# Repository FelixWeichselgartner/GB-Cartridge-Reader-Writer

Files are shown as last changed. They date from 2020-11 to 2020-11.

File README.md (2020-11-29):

# GB-Cartridge-Reader-Writer

This is an Arduino Shield, that can be used to dump GameBoy cartridges. This project is strongly inspired by this project:

* https://www.insidegadgets.com/2011/03/19/gbcartread-arduino-based-gameboy-cart-reader-%E2%80%93-part-1-read-the-rom/
* https://github.com/insidegadgets/GBCartRead

The code in this repo is based on this, however I did a lot of changes to the Arduino code.

shield_top

shield_bottom

# Tested ROMs

| Game | Dump ROM | Dump RAM | Upload RAM |
|---|---|---|---|
| Tetris (no MBC) | yes | N/A | N/A |
| Yoshi's Cookie (MBC1)  | yes | N/A | N/A |
| Pokémon Red (MBC5) | yes | ? | ? |
| Pokémon Yellow (MBC5)  | yes | yes | ? |
| Pokémon TCG (MBC5) | yes | yes | ? |

GBC is not supported so far.

# Eagle Layout for the Arduino shield

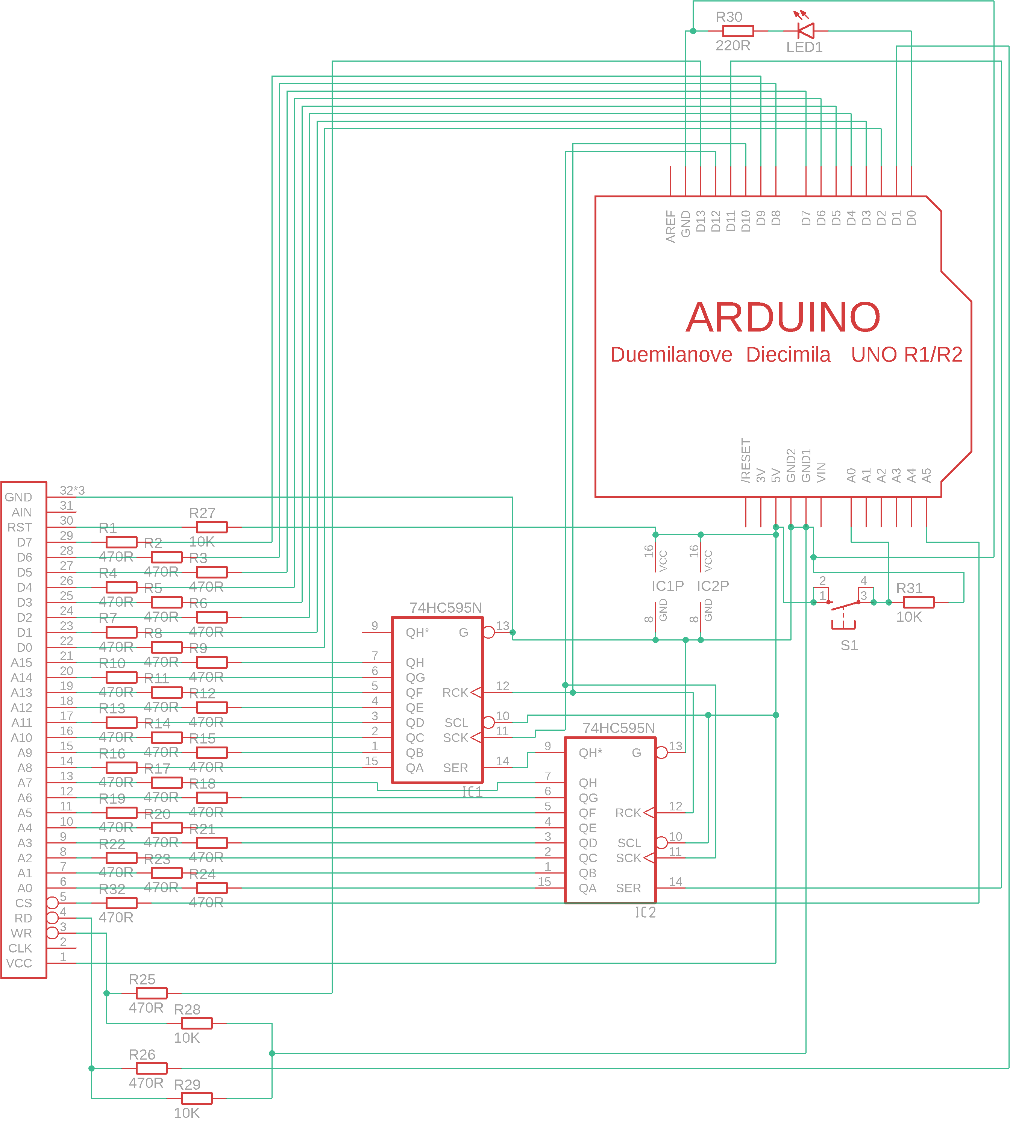
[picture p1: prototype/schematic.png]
schematic


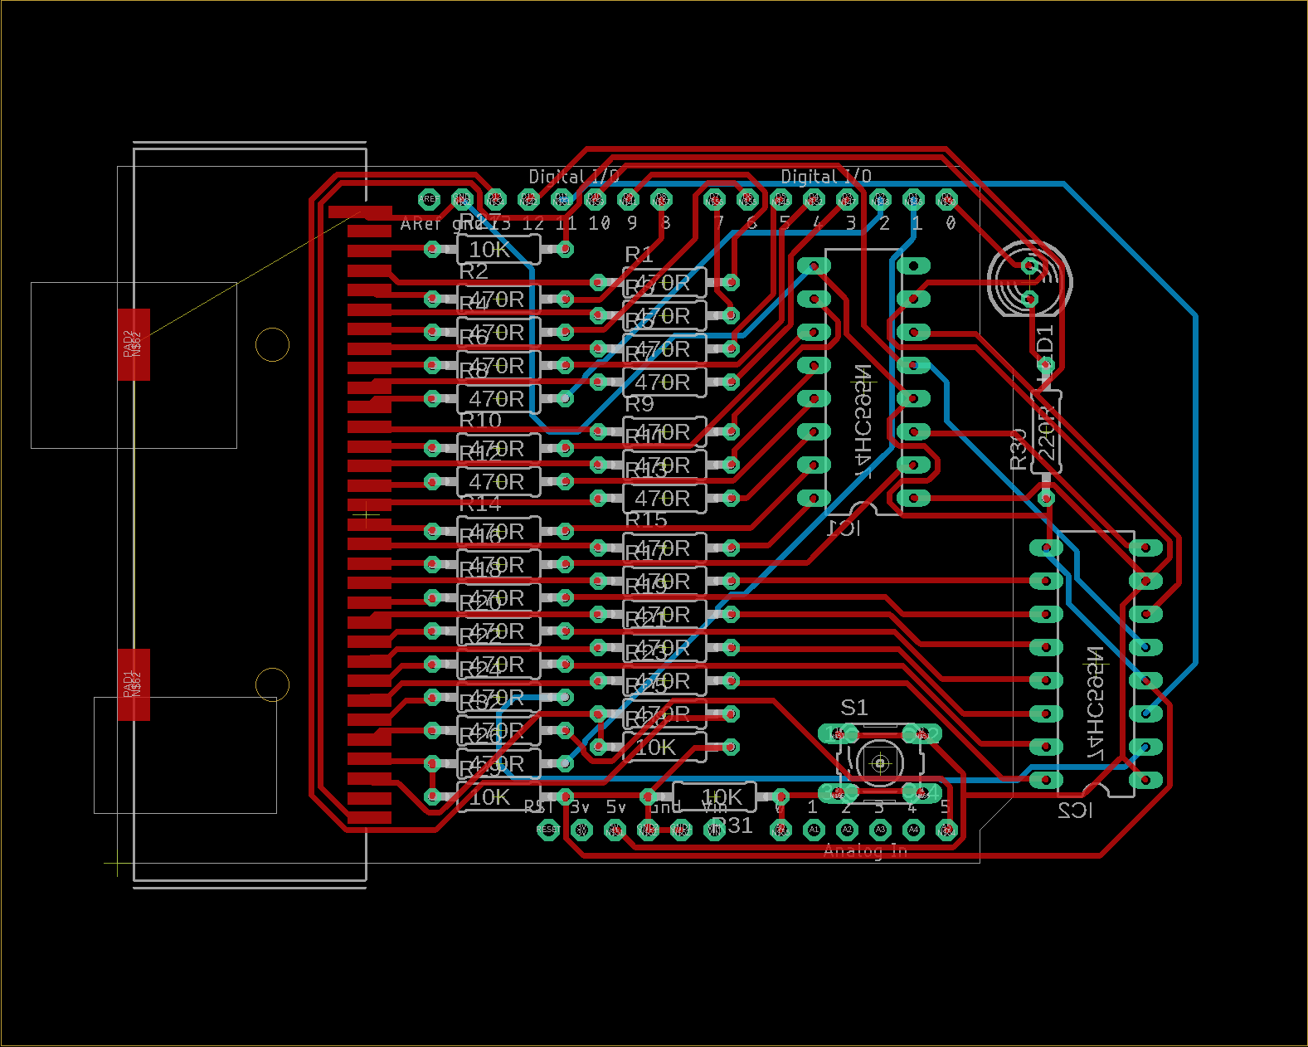
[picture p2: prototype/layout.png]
layout


The bottom layer is supposed to be wired with a simple wire to be able to use a single layer pcb.

Used libraries (see submodules):

* https://github.com/adafruit/Adafruit-Eagle-Library
* https://github.com/robelix/rlx-eagle-libs
* https://github.com/JRodrigoTech/Eagle-Libraries

# License

Copyright (c) 2011-2016 by insideGadgets

Copyright (c) 2019-2020 by Felix Weichselgartner (on the changes)

Creative Commons - Attribution-NonCommercial 3.0 Unported (see License.txt)

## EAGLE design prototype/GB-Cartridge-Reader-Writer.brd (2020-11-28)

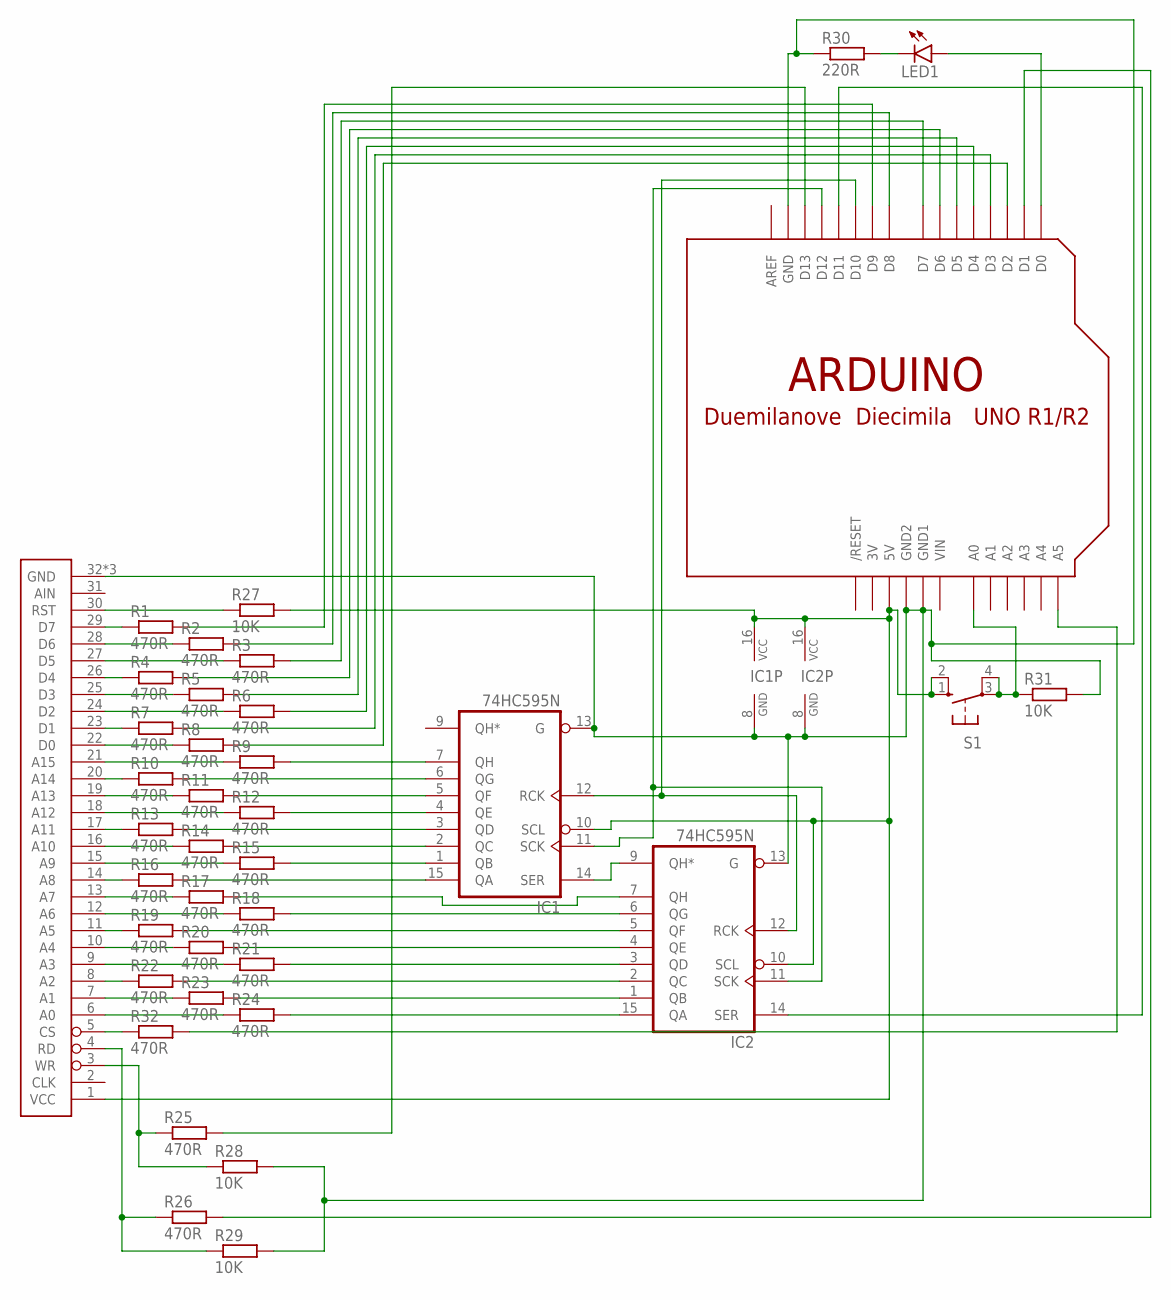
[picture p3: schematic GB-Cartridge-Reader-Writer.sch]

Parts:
IC1, IC2: 74HC595N; DIL16
LED1: LED5MM
R1, R2, R3, R4, R5, R6, R7, R8, R9, R10, R11, R12, R13, R14, R15, R16, R17, R18, R19, R20, R21, R22, R23, R24, R25, R26, R32: 470R; 0207/10
R27, R28, R29, R31: 10K; 0207/10
R30: 220R; 0207/10
S1: 10-XX; B3F-10XX
U$1: ARDUINO-NOHOLE
U$2: GB-CARTRIDGE-SLOTV3; GB-CARTRIDGE-SLOT-3

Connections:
3V: U$1.3V
unnamed: R1.1, U$2.29 (D7)
unnamed: R2.1, U$2.28 (D6)
unnamed: R3.1, U$2.27 (D5)
unnamed: R4.1, U$2.26 (D4)
unnamed: R5.1, U$2.25 (D3)
unnamed: R6.1, U$2.24 (D2)
unnamed: R7.1, U$2.23 (D1)
unnamed: R8.1, U$2.22 (D0)
unnamed: R9.1, U$2.21 (A15)
unnamed: R10.1, U$2.20 (A14)
unnamed: R11.1, U$2.19 (A13)
unnamed: R12.1, U$2.18 (A12)
unnamed: R13.1, U$2.17 (A11)
unnamed: R14.1, U$2.16 (A10)
unnamed: R15.1, U$2.15 (A9)
unnamed: R16.1, U$2.14 (A8)
unnamed: R17.1, U$2.13 (A7)
unnamed: R18.1, U$2.12 (A6)
unnamed: R19.1, U$2.11 (A5)
unnamed: R20.1, U$2.10 (A4)
unnamed: R21.1, U$2.9 (A3)
unnamed: R22.1, U$2.8 (A2)
unnamed: R23.1, U$2.7 (A1)
unnamed: R24.1, U$2.6 (A0)
unnamed: IC2.15 (QA), R24.2
unnamed: IC2.1 (QB), R23.2
unnamed: R32.1, U$2.5 (CS)
unnamed: IC2.3 (QD), R21.2
unnamed: IC2.4 (QE), R20.2
unnamed: IC2.2 (QC), R22.2
unnamed: IC2.6 (QG), R18.2
unnamed: IC2.7 (QH), R17.2
unnamed: IC2.5 (QF), R19.2
unnamed: IC1.1 (QB), R15.2
unnamed: IC1.2 (QC), R14.2
unnamed: IC1.15 (QA), R16.2
unnamed: IC1.4 (QE), R12.2
unnamed: IC1.5 (QF), R11.2
unnamed: IC1.3 (QD), R13.2
unnamed: IC1.7 (QH), R9.2
unnamed: R1.2, U$1.D9
unnamed: IC1.11 (SCK), IC2.11 (SCK), U$1.D12
unnamed: R27.1, U$2.30 (RST)
unnamed: R25.1, R28.1, U$2.3 (WR)
unnamed: R5.2, U$1.D5
unnamed: R26.2, U$1.D1
unnamed: R7.2, U$1.D3
unnamed: R8.2, U$1.D2
unnamed: IC1.14 (SER), IC2.9 (QH*)
unnamed: LED1.A, U$1.D0
unnamed: IC1.10 (SCL), IC1.16 (VCC), IC2.10 (SCL), IC2.16 (VCC), R27.2, S1.1 (S), S1.2 (S1), U$1.5V, U$2.1 (VCC)
unnamed: R6.2, U$1.D4
unnamed: R25.2, U$1.D13
unnamed: R4.2, U$1.D6
unnamed: R3.2, U$1.D7
unnamed: R2.2, U$1.D8
unnamed: LED1.K (C), R30.2
unnamed: IC1.12 (RCK), IC2.12 (RCK), U$1.D10
unnamed: IC1.6 (QG), R10.2
unnamed: IC2.14 (SER), U$1.D11
unnamed: IC1.8 (GND), IC1.13 (G), IC2.8 (GND), IC2.13 (G), R28.2, R29.2, R30.1, R31.2, U$1.GND, U$1.GND1, U$1.GND2, U$2.32 (GND), U$2.PAD1 (GND), U$2.PAD2 (GND)
unnamed: R26.1, R29.1, U$2.4 (RD)
unnamed: R32.2, U$1.A5
unnamed: R31.1, S1.3, S1.4 (P1), U$1.A0
VIN: U$1.VIN

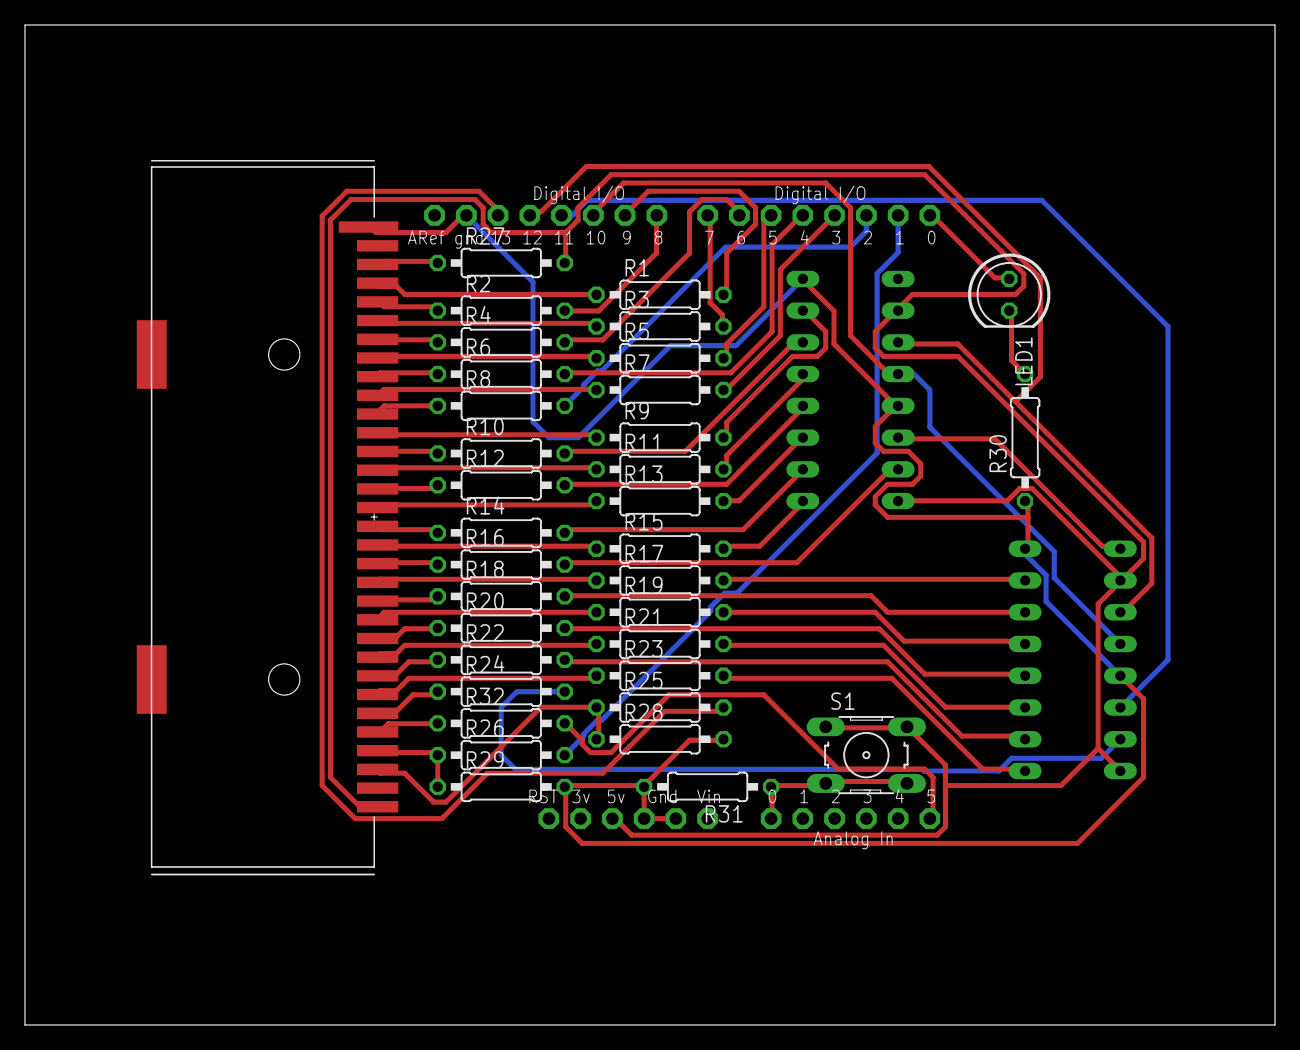
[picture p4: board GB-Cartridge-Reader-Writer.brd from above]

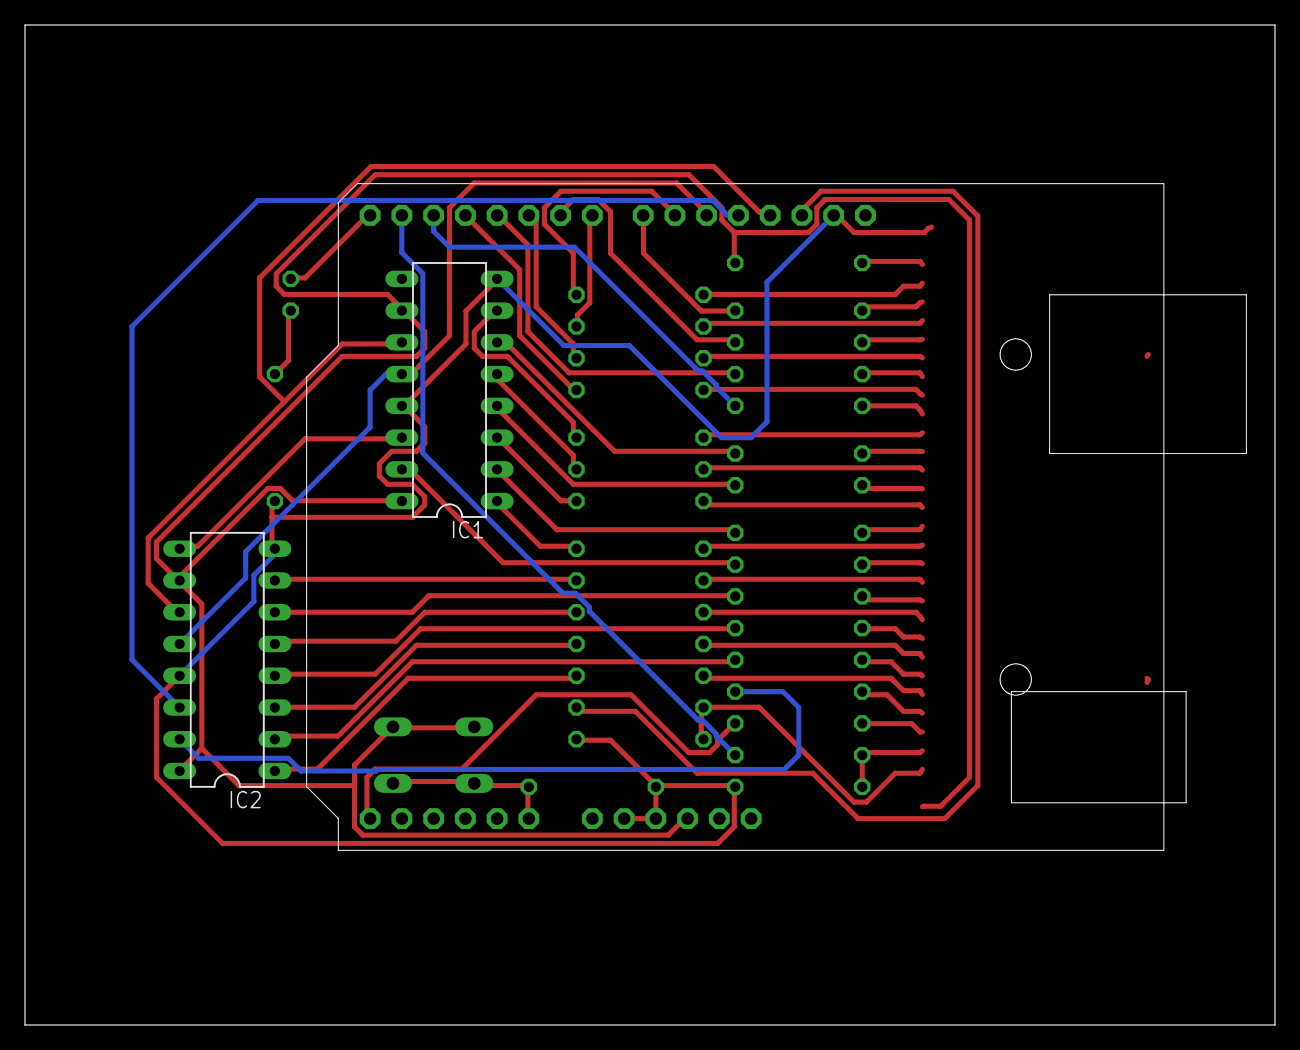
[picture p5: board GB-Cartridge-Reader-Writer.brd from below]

Board: 2 copper layers, 100.0 x 80.0 mm, 38 parts (2 on the bottom side), 64 nets.

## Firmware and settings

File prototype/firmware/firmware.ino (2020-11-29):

/*
 GBCartRead
 Version: 1.6 Rev 1
 Author: Alex from insideGadgets (http://www.insidegadgets.com)
 Created: 18/03/2011
 Last Modified: 17/02/2014
 
 GBCartRead is an Arduino based Gameboy Cartridge Reader which uses a C program or python script to interface with 
 the Arduino. GBCartRead allows you to dump your ROM, save the RAM and write to the RAM.

 Works with Arduino Duemilanove and Uno. Will work for 5V Arduinos but requires wiring changes.

 Speed increase thanks to Frode vdM. (fvdm1992@yahoo.no) and David R

 ***********************************************

 Some changes made by Felix Weichselgartner.
 
*/

// Shield
int ledPin = A3;

#include "Cartridge.hpp"
Cartridge cartridge;

void led_high() {
    digitalWrite(ledPin, HIGH);
}

void led_low() {
    digitalWrite(ledPin, LOW);
}

void setup() {
    Serial.begin(115200);
    pinMode(ledPin, OUTPUT);
}

void loop() {
    // Wait for serial input
    while (Serial.available() <= 0) {
        led_high();
        delay(200);
    }

    led_low();
    
    // Decode input
    char readInput[10];
    int readCount = 0;
    while (Serial.available() > 0) {
        char c = Serial.read();
        readInput[readCount] = c;
        readCount++;
    }
    readInput[readCount] = '\0';
    
    cartridge.ReadHeader();
    
    // Cartridge Header
    if (strstr(readInput, "HEADER")) {
        cartridge.SerialPrintHeader();
    }
    // Dump ROM
    else if (strstr(readInput, "READROM")) {
        cartridge.DumpROM();
    }
    // Read RAM
    else if (strstr(readInput, "READRAM")) {
        cartridge.DumpRAM();
    }
    // Write RAM
    else if (strstr(readInput, "WRITERAM")) {
        cartridge.UploadRAM();
    }
}

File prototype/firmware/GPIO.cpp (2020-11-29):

#include "GPIO.hpp"

GPIO::GPIO() { 
    this->shiftregister = new ShiftRegister74HC595(2, this->dataPin, this->clockPin, this->latchPin);

    // data pins.
    this->dataInput();

    pinMode(wrPin, OUTPUT);
    pinMode(rdPin, OUTPUT);
    pinMode(csPin, OUTPUT);

    this->wr_high();
    this->rd_high();
    this->cs_high();
}

void GPIO::setAddress(Word address) { 
    for (int i = 0; i < 16; i++) {
        shiftregister->setNoUpdate(i, ((address & 0xFFFF) & (1 << i)) == (1 << i));
    }
    shiftregister->updateRegisters();
}

Byte GPIO::getByte(Word address) {
    this->setAddress(address);
    this->rd_low();
    this->cs_low();
    delayMicroseconds(10);

    Byte val = 0x00;
    for (int i = 0; i < 8; i++) {
        if (digitalRead(dataPins[i])) {
            val |= (0x01 << i);
        }
    }

    this->rd_high();
    this->cs_high();
    delayMicroseconds(10);
    
    return val;
}

void GPIO::setByte(Word address, Byte data) {
    this->dataOutput();

    setAddress(address);
    for (int i = 0; i < 8; i++) {
        digitalWrite(dataPins[i], data & (0x01 << i));
    }

    this->wr_low();
    delayMicroseconds(10);
    this->wr_high();
    delayMicroseconds(10);

    this->dataInput();
}

void GPIO::wr_low() {
    digitalWrite(wrPin, LOW);
}

void GPIO::wr_high() {
    digitalWrite(wrPin, HIGH);
}

void GPIO::rd_low() {
    digitalWrite(rdPin, LOW);
}

void GPIO::rd_high() {
    digitalWrite(rdPin, HIGH);
}

void GPIO::dataInput() {
    for (int i = 0; i < 8; i++) {
        pinMode(dataPins[i], INPUT);
    }
}

void GPIO::cs_low() {
    digitalWrite(csPin, LOW);
}

void GPIO::cs_high() {
    digitalWrite(csPin, HIGH);
}

void GPIO::dataOutput() {
    for (int i = 0; i < 8; i++) {
        pinMode(dataPins[i], OUTPUT);
    }
}

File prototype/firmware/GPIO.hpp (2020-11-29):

#ifndef GPIO_HPP_
#define GPIO_HPP_

#include "Arduino.h"
#include <ShiftRegister74HC595.h>
#include "datatypes.h"

class GPIO {

public:

    GPIO();

    void setAddress(Word);
    Byte getByte(Word);
    Byte getRAMByte(Word);
    void setByte(Word, Byte);

    void wr_low();
    void wr_high();
    void rd_low();
    void rd_high();
    void cs_low();
    void cs_high();

    void dataInput();
    void dataOutput();

private:

    // ShiftRegisters
    int latchPin = 10;
    int dataPin = 11;
    int clockPin = 12;
    // Cartridge
    int rdPin = A1;
    int wrPin = 13;
    int csPin = A4;
    int dataPins[8] = {2, 3, 4, 5, 6, 7, 8, 9};

    ShiftRegister74HC595 *shiftregister;

};

#endif

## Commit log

2019-05-16 prototype with: smd->cart-adapter, tht->R,LED,BUTTON,SHIFT-REGISTERS
    [GB-Cartridge-Reader-Writer.brd, GB-Cartridge-Reader-Writer.sch]
2019-05-18 moved some components - no functionial changes
    [GB-Cartridge-Reader-Writer.brd, GB-Cartridge-Reader-Writer.sch]
2019-06-01 made traces wider; wired wire bridges on bottom layer to get the vias for drilling; more space between traces;
    [GB-Cartridge-Reader-Writer.brd, GB-Cartridge-Reader-Writer.sch]
2019-06-17 moved one ic due to space issues
    [GB-Cartridge-Reader-Writer.brd]
2019-08-03 firmware and python-interface - not working so far; shift-regs working, buttons & led working, error unknown
    [firmware.ino, interface.py]
2019-10-02 added missing destructor; linux option for com ports
    [Cartridge.cpp, interface.py]
2020-11-28 license, layout improvements, png, submodules, readme
    [GB-Cartridge-Reader-Writer.brd, GB-Cartridge-Reader-Writer.sch]
2020-11-28 added schematic from typo
2020-11-29 added pin tester sketch

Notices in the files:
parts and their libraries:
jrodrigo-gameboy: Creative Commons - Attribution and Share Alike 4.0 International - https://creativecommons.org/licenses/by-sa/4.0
